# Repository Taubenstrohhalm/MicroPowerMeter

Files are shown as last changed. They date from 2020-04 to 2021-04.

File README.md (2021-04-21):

# MicroPowerMeter
 
 MicroPython scriptable, wifi enabled, dc-powermeter (36V x 15A ~ 500W). Build around espressif's ESP8266 soc and TI's INA260 current-sensor. Open Source Hard- & Software.   

#### ... build time: ~ 2h  ... cost: ~ 15 €

## 1. User Guide

The MicroPowerMeter (MPM) can be used, to measure voltages between 0-36 V, currents between 0+-15 A and both current, and voltage at the same time to measure the power consumed by a load or produced by a generator. 

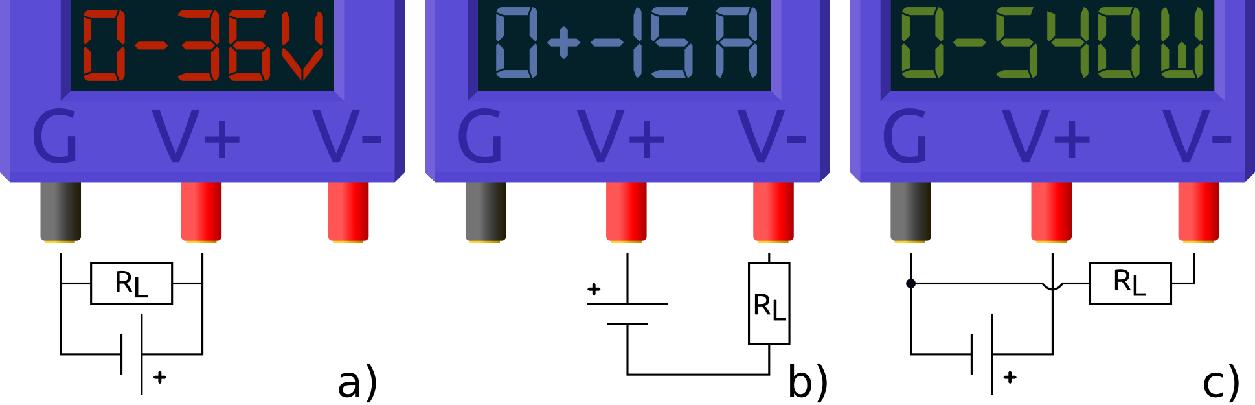
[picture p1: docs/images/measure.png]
header_image


**Measuring: a) voltage, b) current c) power.** 

You can read the measured values on your phone or any wifi enabled device with a webbrowser. Alternativley you can send the values to another webserver and store them to be viewed from somewhere else. A third option is storing the data on the microcontoller to download them later (not jet implemented).

### 1.1 Turn on
You can turn on the MPM by connecting it to a 5V batterypack or a phonecharger. There is no on/off switch, it will turn on immediatly and run the boot.py script. 

### 1.2 Connect
During the boot section the MPM exceptcs a wifi device to connect to the wifi access point with the ssid: "MicroPowerMeter". The password can be found/changed in the boot.py file. *Would be nice if it tried to log in to the last/known wifi network first. Anyone keen to implement that?* 

Once your phone is connected you can open a browser and enter http://192.168.4.1/ in the url-field. 
A get-request for the file index.html will be sent from your phones browser to the microcontroller. The microcontroller resonds by sending back the requested file. In the header section of the index.html file a few other files (.css and .js) are requested and will be send to your browser. When all files are transfered an interval function triggers a get-request every 500ms asking the microcontroller for new sensor data. Once received the ui will update.  

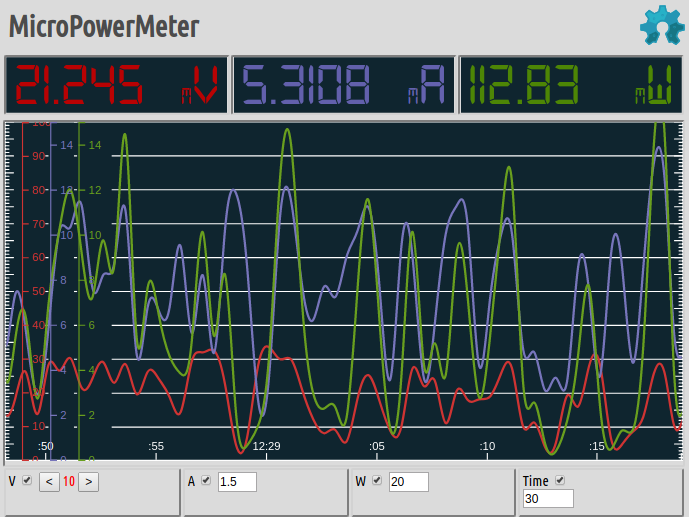
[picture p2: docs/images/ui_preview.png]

Fig.: UI preview filled with [random data](/software/README.md).

# 2. Specifications & Accurency

### - ESP8266 - Microcontroller 
- Vcc = 5V  - so you can use your USB powerbank as supply  
- 4MB Memory - to store captured data (csv/txt)

### - INA260 - Integrated current sensor 
- U_sens = 0 - 36V  
- I_sens = 0 ± 15A + - 1.5mA  
- P_max = U_sens_max * I_sens_max = 540W 

# 3. Build your own - DIY

Building this powermeter will not only give you a handy tool for your electronic projects, it will also help you understand the concepts of current, voltage & electrical power, along with the basics of IoT-devices, sensors and microcontrollers. 

## 3.1 Get the hardware  

All the required parts are listed in the bill of materials (BOM) below. Additionaly you will need a 5V powerbank, a wifi enabled device with some kind of webbrowser and some fillament for the enclosure. 

|Quantity|Part|Image|Description|Price|Shop|
|---|---|---|---|---|---|
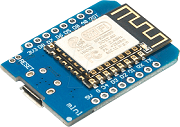
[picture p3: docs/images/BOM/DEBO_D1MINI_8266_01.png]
d1mini
1| D1 mini|| ESP8266 microcontroller on a breakout-board with serial to usb interface|4,99€||
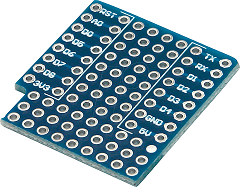
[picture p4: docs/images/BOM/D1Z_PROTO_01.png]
1| D1z proto||prototyping board for the D1 mini *|0,99€||
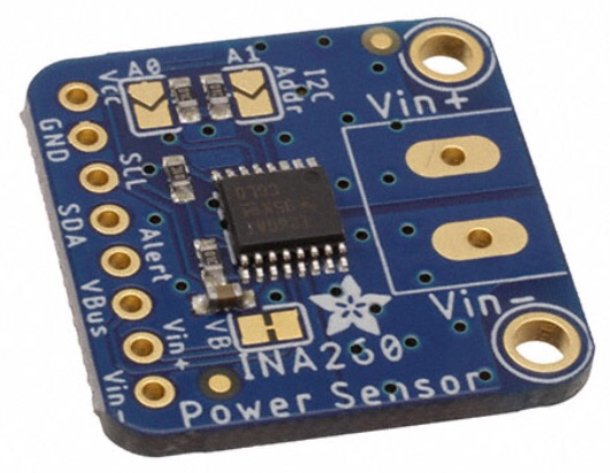
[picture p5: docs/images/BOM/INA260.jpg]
1| INA260||High-Side current sensor devboard. Designed by adafruit.|9,00€
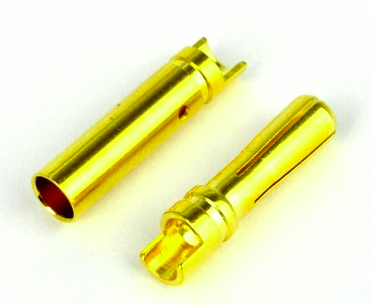
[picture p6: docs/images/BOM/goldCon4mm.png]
3| J_1-3||4mm gold connector female||
1| J4 || 8 x Pinheader male|
1| J5 || wire|  
Table: BOM_v0.10

     * there are different versions of this board available. Only the version shown in the BOM works for this project. You can also use standard prototyping board and cut it to size. 

### Schematic  

The rectangle on the left labeled Wemos D1 mini is the dev board for the esp8266. On this printed circuit board (PCB) sits the ESP8266, a wifi antenna, a reset button, a micro USB-port and the IC for a serial connection to your computer.
On the right you see the breakout board for the current sensor (INA260). In this tiny IC is where the magic happens.

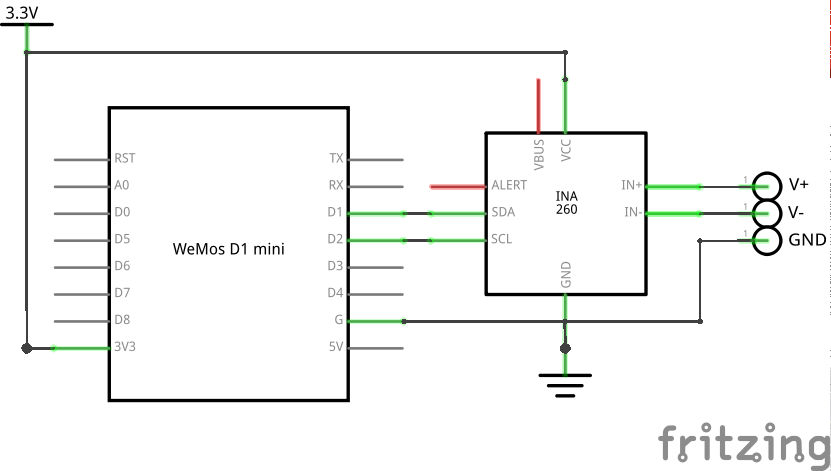
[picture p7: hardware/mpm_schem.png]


### 3.2 Soldering

Assembling the electronics requires some soldering. If you have never soldered before check out this [awesome soldering guide](https://learn.adafruit.com/adafruit-guide-excellent-soldering) by adafruit.

#### 3.2.1. Wemos D1 mini
Solder the two female pin-headers to the wemos D1 mini.

#### 3.2.2. Sensor board
Unfortunatly the sensor can not directly be connected to the Wemos D1 mini. A adapter board is needed. The following pictures show the soldering process of the adapter board. *If you are familiar with KiCAD, or any other e-cad software please consider having a look at the to-do list.*
This might be the most difficult part, (you might want to get a drink before you start.) 

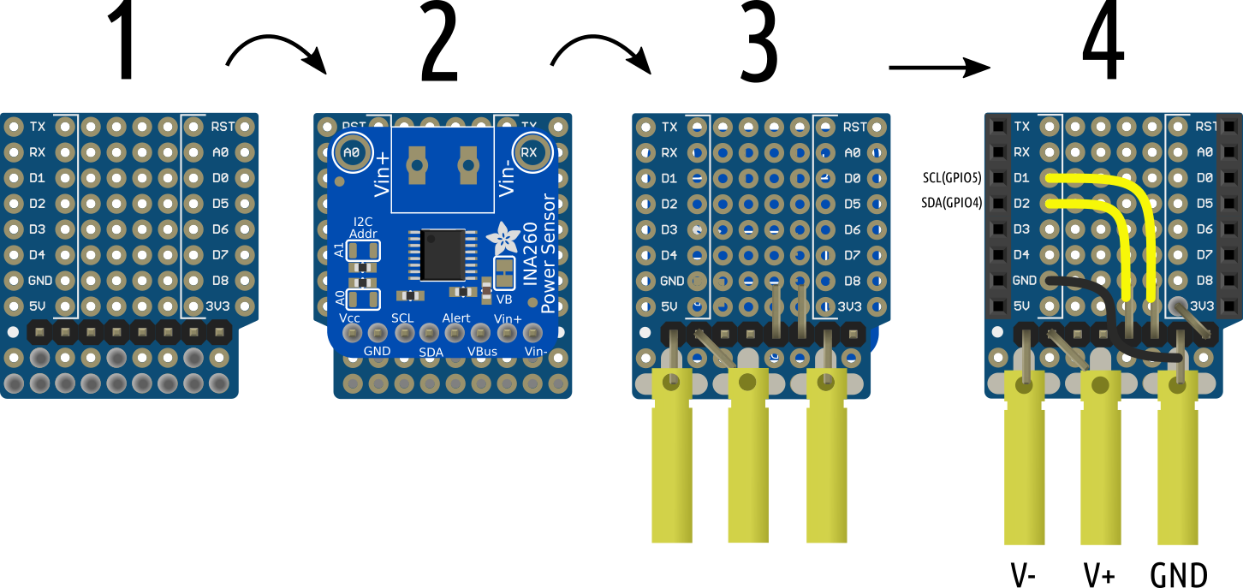
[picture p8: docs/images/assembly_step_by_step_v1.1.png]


#### 3.3 Enclosure

If you have a 3D-printer or the fab-lab is not to far you can print an enclosure for your device. You find the .stl files in the hardware directory of this repo. There is also a Blender file, in case you want to add custom text.

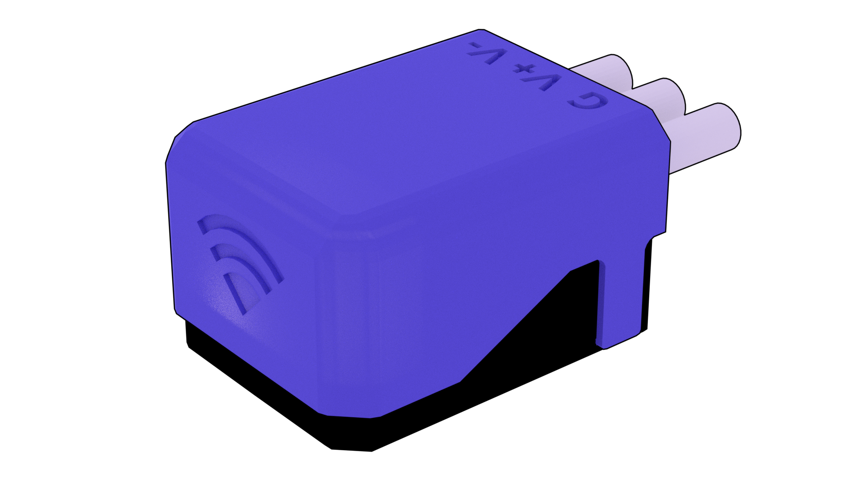
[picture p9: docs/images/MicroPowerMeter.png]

Download CAD-file as [[.blend]](/hardware/enclosure_v1.2.blend)

## 4. Software  

Micropython Firmware  
RESTfull Webserver
 - d3

# Setting the IDE for MicroPython

In order to tell the microcontroller what we want it to do we need to write some code and store it on the microcontroller. We will be using MicroPython as the programming language and Pymakr to communicate with the microcontroller.  
Pymakr is a plugin, available for the code editors Atom and VisualStudio Code (VS-code). Both are free and Open Source and available for Windows, Linux and Mac. This guide will show you how to set up the IDE on a Microsoft Windows using visual studio code.  

## 1. Download & Install VS-code or atom

## 2. Install pymakr plugin
Open VS-code und navigate to the extensions panel. Search for pymakr and click install.

## 3. Flash ESP8266 with MicroPython Firmware 
If this is your first time using micropython please have a look at the more [general guide](https://docs.micropython.org/en/latest/esp8266/tutorial/intro.html).

### 3.1 Download MicroPython firmware.
Search for the latest stable firmware version for the ESP8266 on MicroPythons [Download page](http://micropython.org/download#esp8266) and download the .bin file.  

### 3.2 Download & install esptool
In a terminal type:  
```
$ pip install esptool
``` 

### 3.2 Flashing the firmware file to the MCU

Connect the MCU to your computer and search for the serial port it got connected to.

```
$ dmesg | grep tty  
[   36.460270] usb 3-1: cp210x converter now attached to ttyUSB0
```

What we are looking for is the "ttyUSB0" (on Windows this should be something like "COM0", you can look it up in the device manager)

Now we will first erase the flash of the MCU by typing:
```
esptool.py --port /dev/ttyUSB0 erase_flash
```
Flash the firmware-file to the MCU by typing:

```
esptool.py --port /dev/ttyUSB0 --baud 460800 write_flash --flash_size=detect 0 ~/Downloads/esp8266-20191220-v1.12.bin
```
make sure to replace the serial-port and filename if you downloaded a newer version.

### 3.3 Putting the code on the MCU

Clone or download this repository and open the folder in your editor (VS-code/atom). Open the pymakr.conf file and change the following two lines:

```
"address": "/dev/ttyUSB0",
"sync_folder": "software",
```
The first line tells pymakr on which serial-port to look for the MCU. The second line makes sure only the software files will be uploaded to the MCU.   
Press the "Pycom Console" button at the bottom of your editor to connect to the MCU. (check if the pymakr-plugin is enabled, if you can't find it).  
Then press the "upload" button. After the upload process is done, the MCU will reboot and you can access the webserver by connecting to the WIFI access point called "MicroPowerMeter". The password is "ohms_law". You can change the ssid and the pwd in the file "/Software/boot.py" if you like.

## use - study - share - improve 

Have a look at the **to do list**. If you feel like one of the tasks is yours, you can clone this repo, commit your changes and post a pull request. So fare everything you can find in this repo has been created using free & open source software. If you contribute, it would be great if you follow this pattern.

### To Do's:
+ Documentation
  + add missing parts (D1z proto, 4mm gold connector) to fritzing library & update layout.png
  + write guide on how to send, store and graph measured data on external webserver (for example via mqtt, influxDB, Grafana)
  + write guide on how to use boolean operators in blender to change the text 
+ Firmware
  + use server-sent-events or websockets for sending sensor-data
  + add code for status led's (hearbeat on connect, blink while waiting for connection, etc.)
  + make webserver asynchron
  + allow client to cache static files - to reduce traffic/load time on second connection
  + add proper gzip-ing
  + move sensor reading away from the get-request -> setup a timer
  + write data to .csv file
  + add proper logging
  + function complete library for ina260
+ Web-Frontend
  + integrate webREPL in UI
  + improve UI (please post inspiration in issue
  + add user guide
+ Hardware
  + design stackable enclosure 
  + design custom pcb for INA260 to replace D1z proto and adafruit INA260 (reduce cost, size and assembly time)

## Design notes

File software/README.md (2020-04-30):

# Testing the UI (without MCU)

### 1. Clone or download this repo.
### 2. Open the file "../software/index.html" and add the following lines at the top of the setInterval() function:

```js
let voltage = Math.random()*36; // generate random value between 0-36 (V)
let current = Math.random()*15; // generate random value between 0-15 (A)
```
### 3. In the same function uncomment the line. 
```js
// getData();
```

### 4. In a terminal navigate to the "/www" folder and type:
```
$ cd software/www/
$ python -m http.server
```
### 5. Open your favourite browser and enter localhost:8000 in the url field.

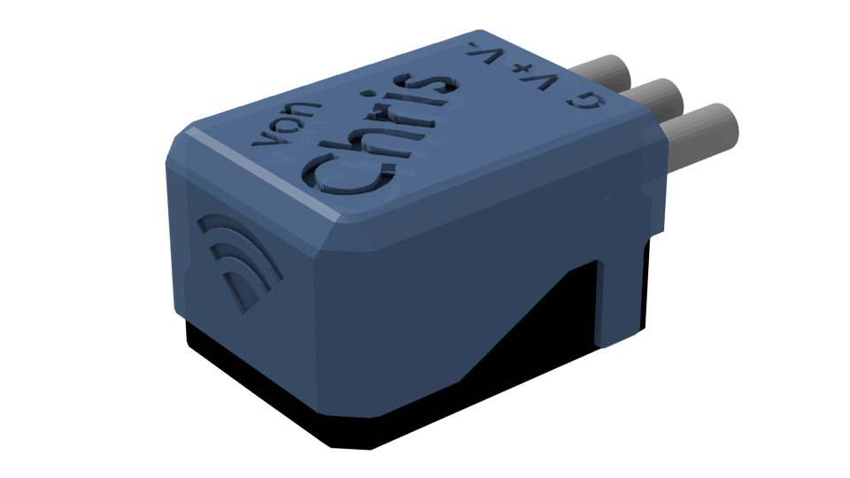
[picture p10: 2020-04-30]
hardware/enclosure.png

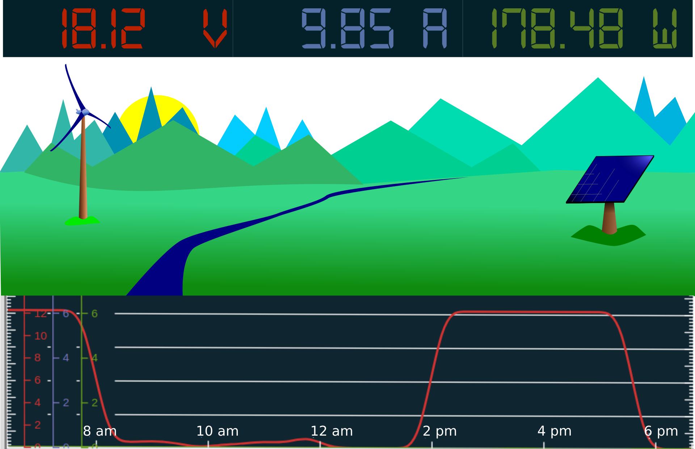
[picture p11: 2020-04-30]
docs/images/header.png

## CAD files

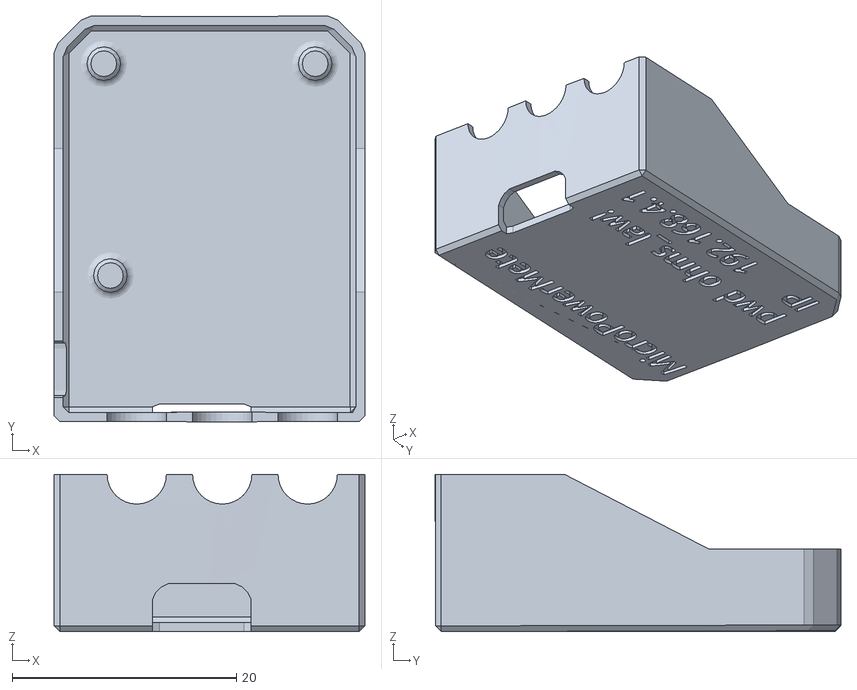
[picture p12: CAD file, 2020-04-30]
hardware/stl/enclosure_bottom_v1.1.stl
27.7 x 36.2 x 14.0

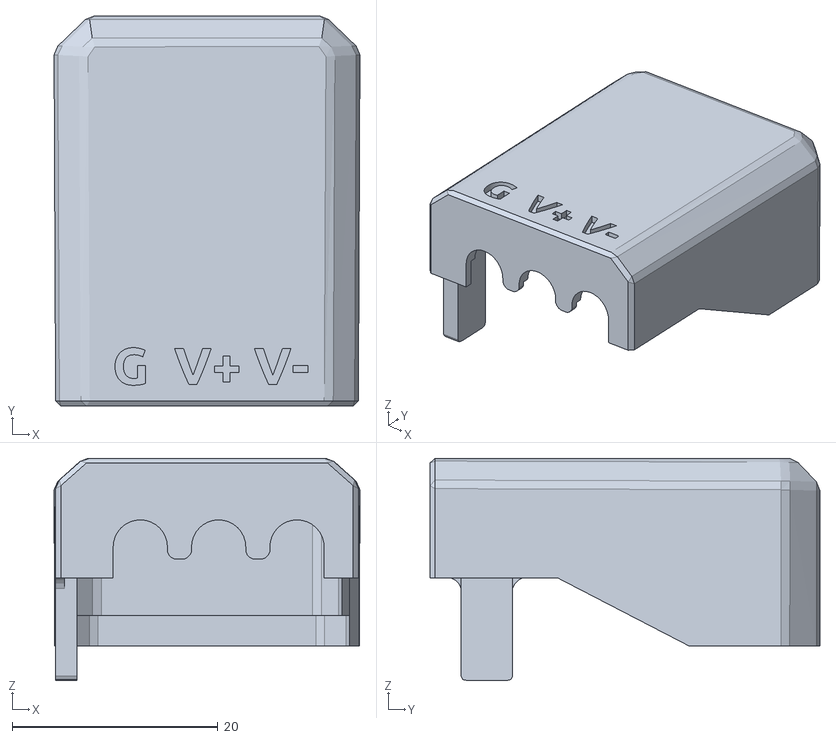
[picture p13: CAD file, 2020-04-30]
hardware/stl/enclosure_top_v1.1.stl
29.7 x 37.9 x 21.6

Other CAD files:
hardware/enclosure_v1.2.blend

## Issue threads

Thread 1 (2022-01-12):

What Open Source License is this under?

timmwille, 2022-01-12:
Nice project, what License is the Hardware and Software under?

examples:
GPLv3 vs. MIT for Software

CC-BY-SA 4.0 vs. CERN OHL P 2.0 for Hardware

etc.

Taubenstrohhalm, 2022-01-13:
Hey Timm!

Thank you for the issue and your question. I'm glad you like the project. Today I would not encourage anyone to rebuild this project, except than for educational purposes.
A multimeter with network connection can be build much simpler with tools like Tasmota or ESPHome.
This being said I really don't care what kind of licence Hard and Software have. You can do what ever you want with it.

I would however like to make this project compliant with current standards for open source soft and hardware. Can you give me some advice where I could find information on such standards?

timmwille, 2022-01-14:
I guess if you want to leave it as simple as possible you go for a permissive license in both cases, you can start picking one here:
https://choosealicense.com/

The GitHub License Templates (when you create a new File called LICENSE or LICENSE.md the option appears) only have typical Software Licenses available as MIT License might be the right one in your case.

Though if you want your Hardware to have a different License, you can include a separate file in the hardware folder to specify that. Say you want to have a more strict "stay open at all times" policy you're probably looking at a "copyleft" license such as typically used CC-BY-SA 4.0 (Share Alike is the key) but this is up to date not the best Hardware License out there anymore, still used mostly though: https://choosealicense.com/licenses/cc-by-sa-4.0/

If you want to go for something more advanced/up to date: https://cern-ohl.web.cern.ch/home

Speaking of Standard also have a look here: https://gitlab.com/OSEGermany/OHS-3105

>If you consider nesting (so the repo has MIT LICENSE but the Hardware should have a different one) you need to point this out and add a license text file respectively to the directory you want it to apply (so in case someone forks or clones the repo it is included).

Closed 2022-03-16.

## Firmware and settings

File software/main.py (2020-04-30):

from machine import Pin, I2C
#import Signal
gc.collect()
import uos as os
gc. collect()
#import uzlib
#gc.collect()
import usocket as socket
gc. collect()
import ujson
gc.collect()
import random
#from ina260 import INA260
from ina219_m import INA219
gc. collect()


# configure builtin LED pin as output-pin und turn it on (low-active)
led_pin = Pin(2,Pin.OUT)
led_pin.off()

#sensor_data = [2] # array to store sensor data
#read_sensor_interval = 200 # interval at which to update the sensor data

i2c = I2C(sda = Pin(4), scl = Pin(5))
#ina = INA260(i2c)
ina = INA219(0.1,i2c)
ina.configure()


webroot = 'www'
compressed = False

def return_file(file_path):
  try:
    with open(file_path, 'r') as file:
      content = file.read()
    #print('Returning {}'.format(file_path))
    return content
  except:
    print('Error reading file')

s = socket.socket(socket.AF_INET, socket.SOCK_STREAM)
s.bind(('', 80))
s.listen(5)

while True:
  conn, addr = s.accept()
  print('Got a connection from %s' % str(addr))
  request = conn.recv(1024)
  request = request.decode('utf-8')
  headerFields = request.split('\r\n')

  requested_file = webroot + headerFields[0].split()[1]
  print('Requested resource: {}'.format(requested_file))

# check if the requested file exists 
  try:
    os.stat(requested_file)
    fexists = True
  except:
    #logging.debug('the requested file does not exist')
    fexists = False

# assign media type (mime_type) to requested file
  if fexists == True:
    file_type = requested_file.split('.')[-1]
    # check if a gziped version of the file was requested
    if file_type == 'gz':
      file_type = requested_file.split('.')[-2]
      compressed = True
    else:
      compressed = False
    if file_type == 'css':
      mime_type = 'text/css'
    elif file_type == 'svg':
      mime_type = 'image/svg+xml'
    elif file_type == 'js':
      mime_type = 'text/javascript'
  #print('Mime_type: {}'.format(mime_type))

# handle get request for / (index.html)
  if headerFields[0] == 'GET / HTTP/1.1':
    conn.send('HTTP/1.1 200 OK\n')
    conn.send('Content-Type: text/html\n')
    conn.send('Connection: close\n\n')
    conn.sendall(return_file('/' + webroot + '/index.html'))
    conn.close()

# handle get requests for all other file types (css / js / images)
  elif fexists == True:
    conn.send('HTTP/1.1 200 OK\n')
    conn.send('Content-Type:' + mime_type + '\n')
    if compressed == True:
      conn.send('Content-Encoding: gzip\n')
    conn.send('Connection: close\n\n')
    gc.collect()
    conn.sendall(return_file(requested_file))
    conn.close()
    gc.collect()

# handle get request for updating the sensor data
  elif headerFields[0] == 'GET /update HTTP/1.1':
    voltage = ina.voltage()*1000 # ina219 returns V while ina260 returns mV 
    current = ina.current()
    power = ina.power()
    # uncomment the following lines to test without sensor
    # voltage = random.getrandbits(15)
    # current = random.getrandbits(14)
    # power = voltage * current
    conn.send('HTTP/1.1 202 OK\n')
    conn.send('Content-Type: application/json\n')
    conn.send('Connection: close\n\n')
    conn.send(ujson.dumps({ "voltage":voltage,
                            "current":current,
                            "power":power
                            }))
    conn.close()

  else:
    conn.send('HTTP/1.1 404 ERROR\n')
    conn.close()

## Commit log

2020-04-30 add: docu and software
    [enclosure_bottom_v1.1.stl, enclosure_top_v1.1.stl]
2020-05-01 add: blend file
    [enclosure_v1.2.blend]
